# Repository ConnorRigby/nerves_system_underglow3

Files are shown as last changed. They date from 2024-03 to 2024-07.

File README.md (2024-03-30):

# ConeRGB Underglow3 Nerves Support



This is the base Nerves System configuration for [ConeRGB V3](https://github.com/connorrigby/underglow3).

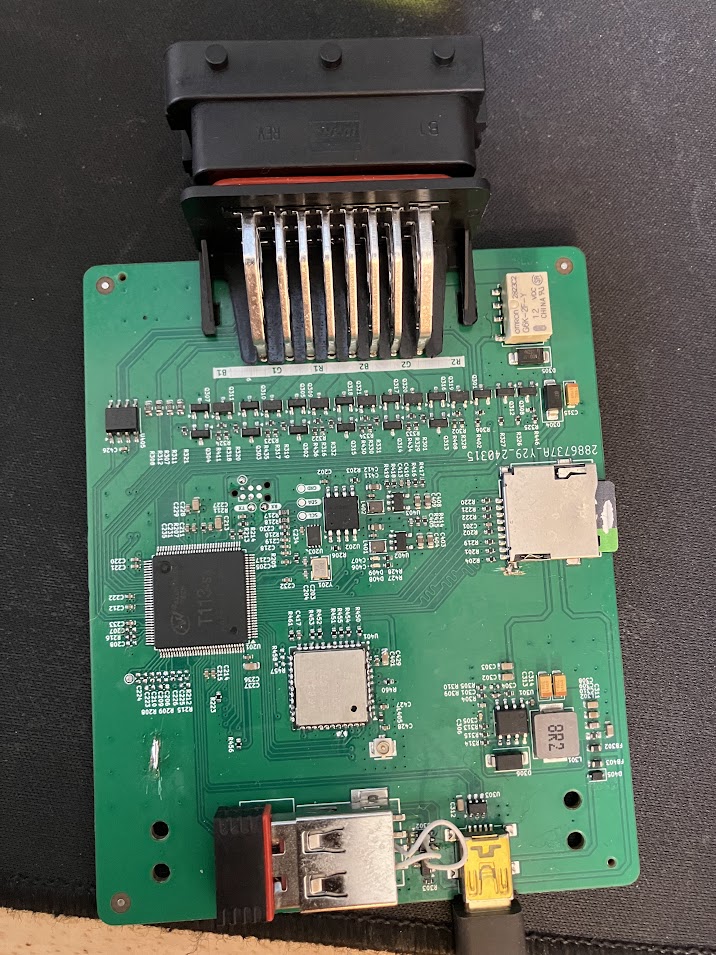
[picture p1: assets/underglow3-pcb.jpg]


| Feature | Description |
| --- | --- |
| CPU | 1.2 GHz ARM Cortex-A7 Dual-Core |
| Memory | 128 MB DDR3 |
| Storage | MicroSD |
| Linux kernel | 6.1 w/ patches |
| IEx terminal | UART `ttyS0` |
| GPIO, I2C, SPI | Yes - [Elixir Circuits](https://github.com/elixir-circuits) |
| Display | No |
| ADC | No |
| PWM | 8 channels |
| UART | ttyS0 |
| Camera | No |
| Ethernet | No |
| WiFi | Onboard WiFi |
| RTC | No |
| HW Watchdog | Yes |

## Special Thanks

Most of the hard work in this repo was gleamed from [YuzukiSBC](https://github.com/YuzukiHD/Buildroot-YuzukiSBC)

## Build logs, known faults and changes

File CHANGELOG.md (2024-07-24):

# Changelog

This project does NOT follow semantic versioning. The version increases as
follows:

1. Major version updates are breaking updates to the build infrastructure.
   These should be very rare.
2. Minor version updates are made for every major Buildroot release. This
   may also include Erlang/OTP and Linux kernel updates. These are made four
   times a year shortly after the Buildroot releases.
3. Patch version updates are made for Buildroot minor releases, Erlang/OTP
   releases, and Linux kernel updates. They're also made to fix bugs and add
   features to the build infrastructure.

## v0.3.0

Third prototype Bringup release

* Enable BlueZ
* Enable RTL WiFi

## v0.2.0

Second prototype Bringup release

* Enable ledc
* Enable temporary rtl wifi driver
* Enable kernel bluetooth
* Enable ipv6

## v0.1.0

This is the initial release.

* WiFi+BT does not work yet. next pcb revision required for brcmfmac.
* PWM works, leds in device tree. likely will change.
* LEDC works, leds in device tree. likely will change.
* user input configured but not tested.
* linux v6.7.1
* uboot 2024.04-rc4
* nerves_system_br v1.27.0

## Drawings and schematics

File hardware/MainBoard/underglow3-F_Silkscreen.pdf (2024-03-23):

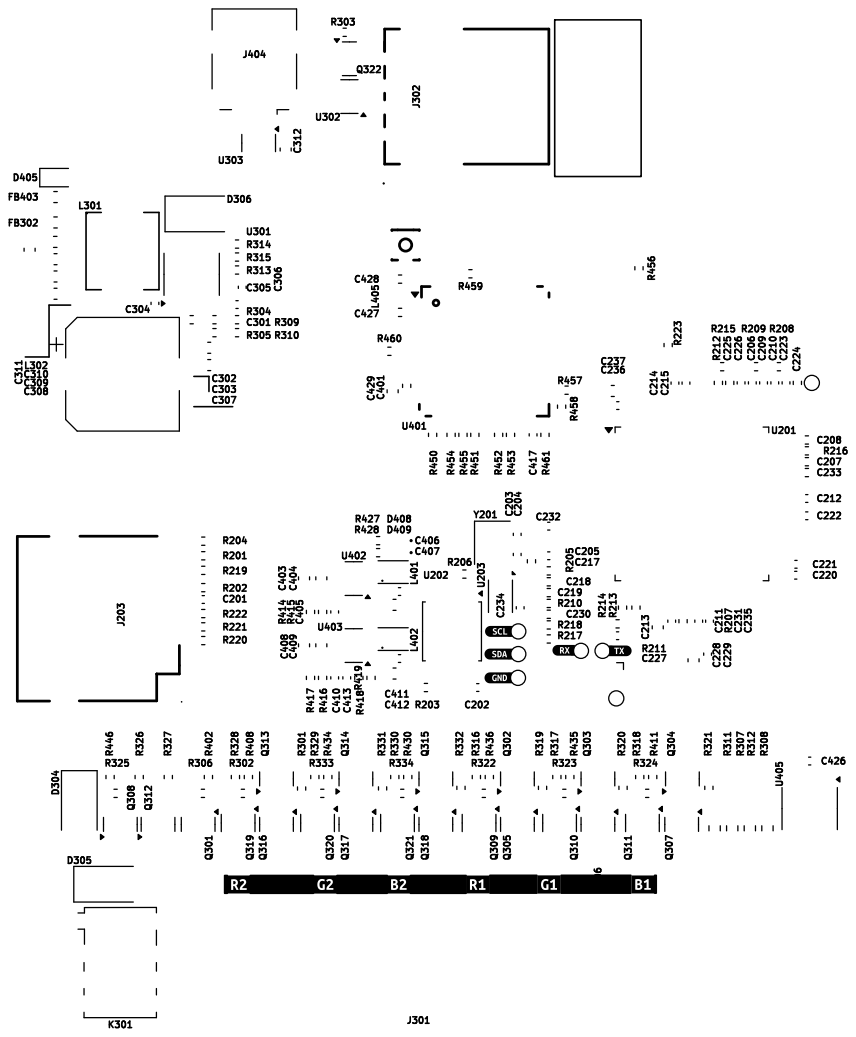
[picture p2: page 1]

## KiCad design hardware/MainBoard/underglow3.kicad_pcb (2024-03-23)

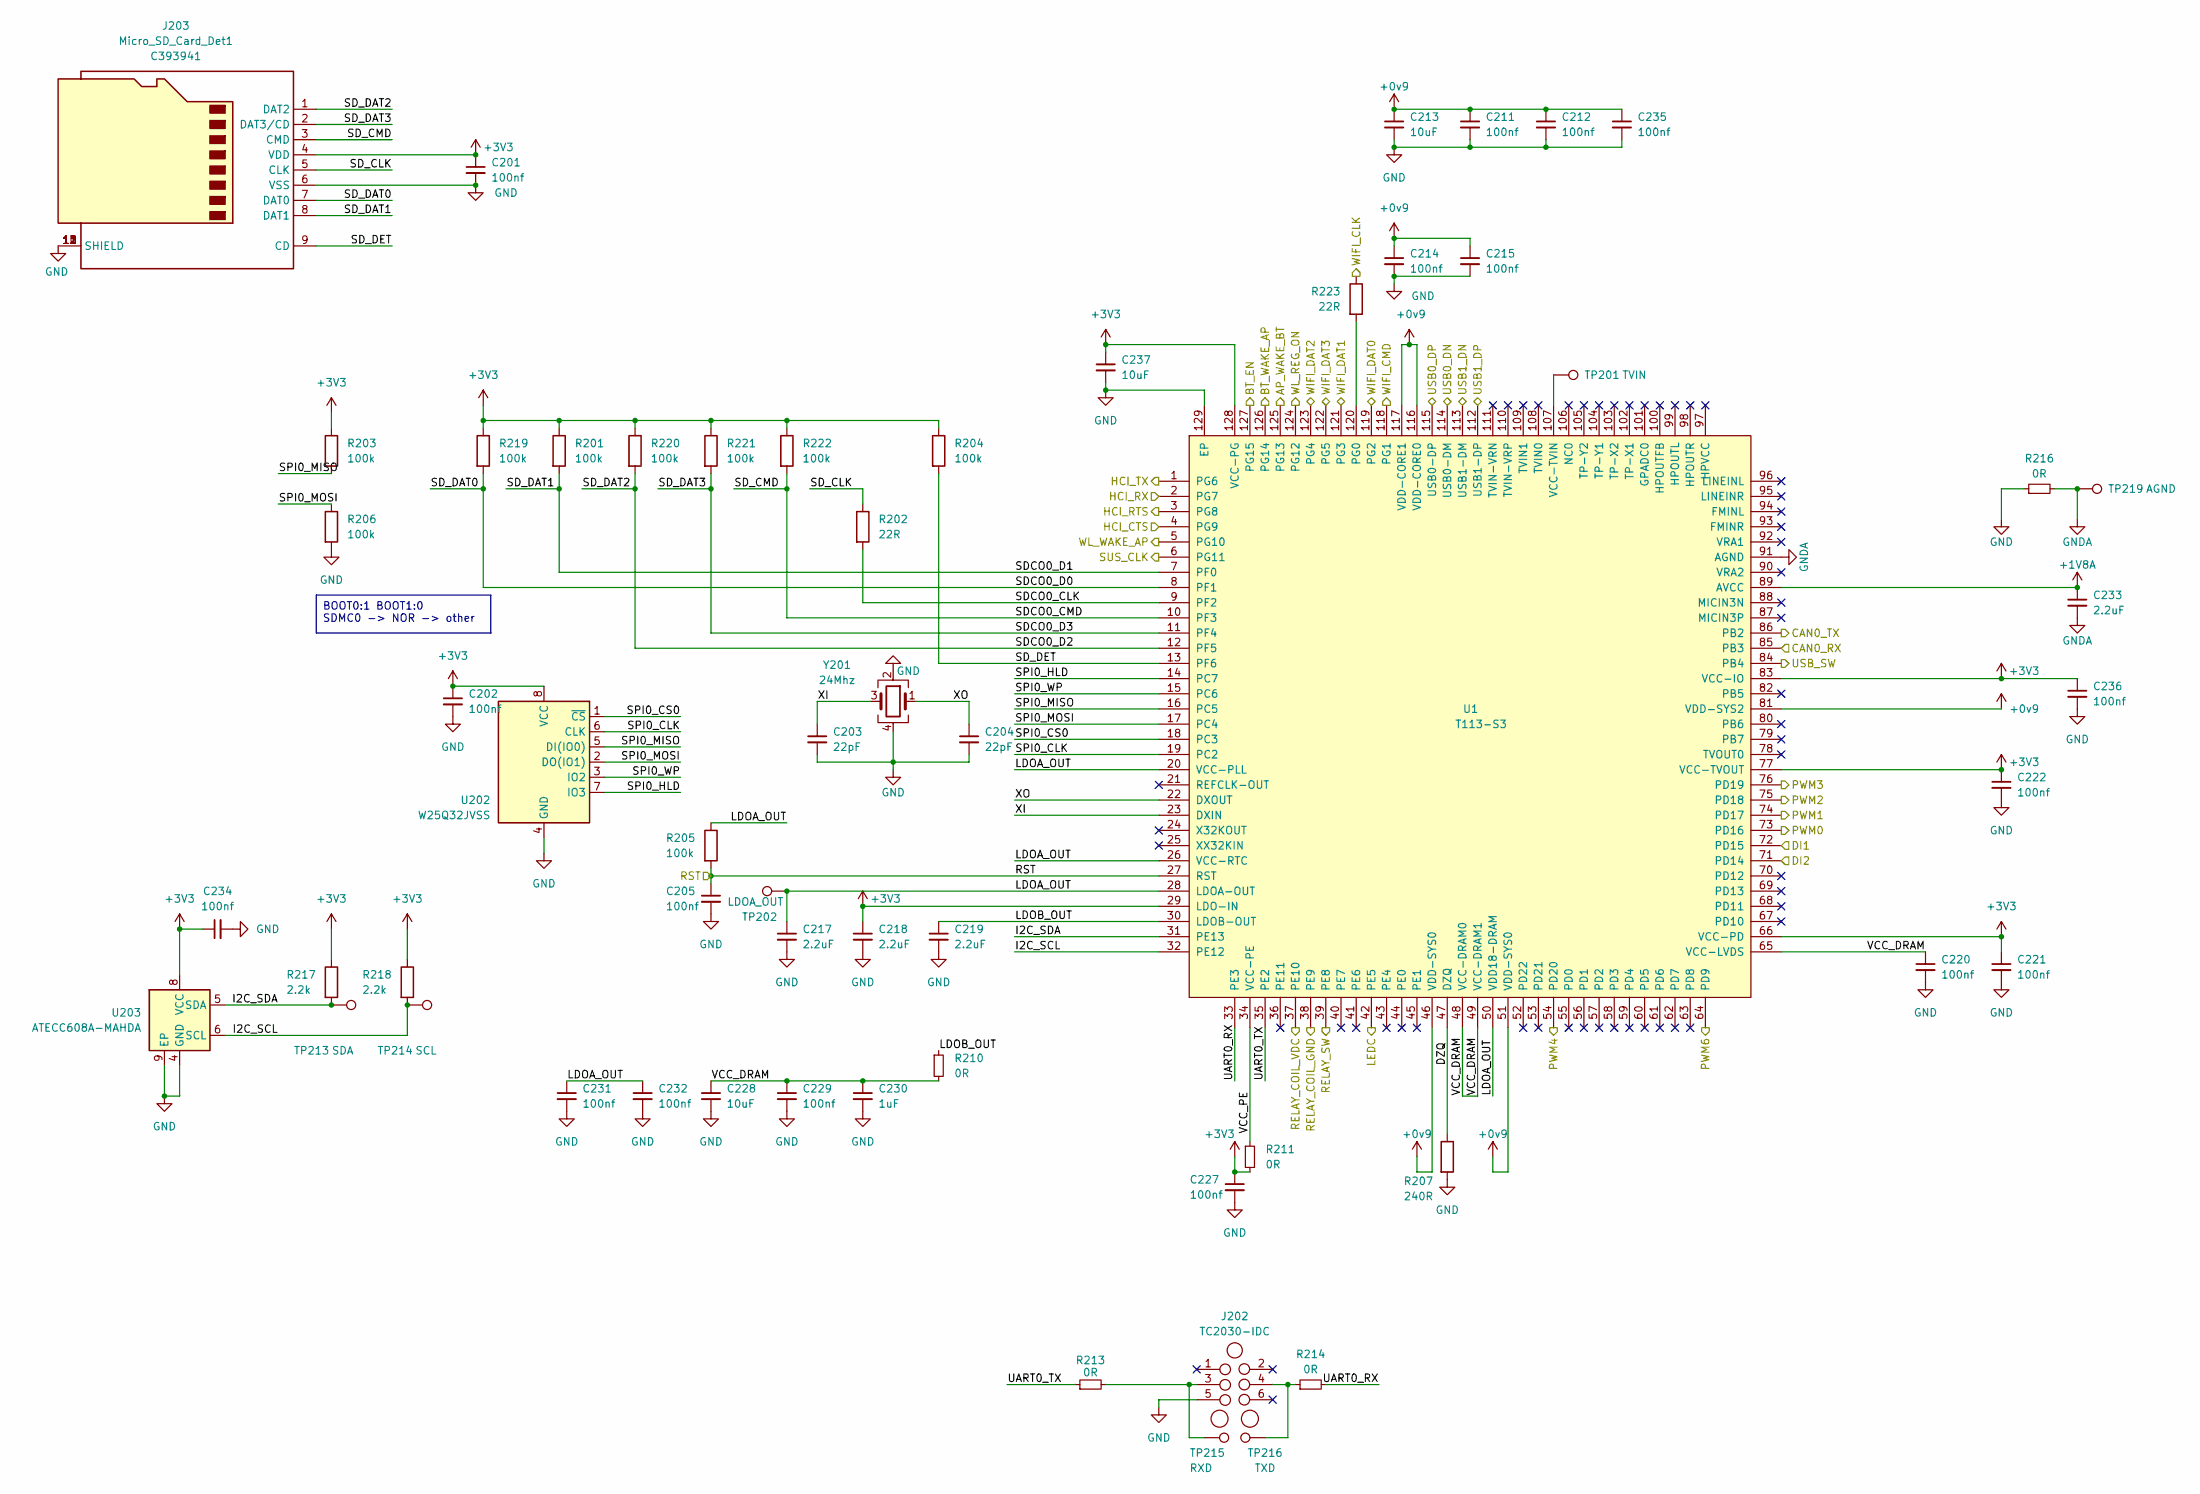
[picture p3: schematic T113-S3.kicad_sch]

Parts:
C201, C202, C205, C211, C212, C214, C215, C220, C221, C222, C227, C229, C231, C232, C234, C235, C236: 100nf; C_0402_1005Metric; MPN CL05B104KB54PNC; LCSC C307331
C203, C204: 22pF; C_0402_1005Metric; MPN 0402CG220J500NT; LCSC C1555
C213, C228, C237: 10uF; C_0603_1608Metric; MPN CL10A106MA8NRNC; LCSC C96446
C217, C218, C219, C233: 2.2uF; R_0402_1005Metric; MPN CL05A225MQ5NSNC; LCSC C12530
C230: 1uF; R_0402_1005Metric; MPN CL05A105KA5NQNC; LCSC C52923
J202: TC2030-IDC; Tag-Connect_TC2030-IDC-NL_2x03_P1.27mm_Vertical
J203: Micro_SD_Card_Det1; TF-SMD_TF-PUSH; MPN TF PUSH; LCSC C393941
R201, R203, R204, R205, R206, R219, R220, R221, R222: 100k; R_0402_1005Metric; MPN 0402WGF1003TCE; LCSC C25741
R202, R223: 22R; R_0402_1005Metric; MPN 0402WGF220JTCE; LCSC C25092
R207: 240R; R_0402_1005Metric; MPN 0402WGF2400TCE; LCSC C25094
R210, R211, R213, R214, R216: 0R; R_0402_1005Metric; MPN 0402WGF0000TCE; LCSC C17168
R217, R218: 2.2k; R_0402_1005Metric; MPN 0603WAF2201T5E; LCSC C4190
TP201: TVIN; TestPoint_Pad_D1.0mm
TP202: LDOA_OUT; TestPoint_Pad_D1.0mm
TP213: SDA; TestPoint_Pad_D1.0mm
TP214: SCL; TestPoint_Pad_D1.0mm
TP215: RXD; TestPoint_Pad_D1.0mm
TP216: TXD; TestPoint_Pad_D1.0mm
TP219: AGND; TestPoint_Pad_D1.0mm
U1: T113-S3; LQFP-128_L14.0-W14.0-P0.40-LS16.0-BL-EP5.6; MPN T113-S3; LCSC C5197687
U202: W25Q32JVSS; SOIC-8_5.23x5.23mm_P1.27mm; MPN W25Q32JVSSIQ; LCSC C179173
U203: ATECC608A-MAHDA; DFN-8-1EP_3x2mm_P0.5mm_EP1.3x1.5mm; MPN ATECC608A-MAHDA-S; LCSC C616908
Y201: 24Mhz; Crystal_SMD_3225-4Pin_3.2x2.5mm; MPN 3TJ424000XYFBC; LCSC C2149059

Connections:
+0v9: C211.1, C212.1, C213.1, C214.1, C215.1, C235.1; also elsewhere on the board
+1V8A: C233.1; also elsewhere on the board
+3V3: C201.1, C202.1, C218.1, C221.1, C222.1, C227.1, C234.1, C236.1, C237.1, J203.4 (VDD), R201.1, R203.1, R204.1, R211.2, R217.1, R218.1, R219.1, R220.1, R221.1, R222.1, U202.8 (VCC), U203.8 (VCC); also elsewhere on the board
/Application/DZQ: R207.1; also elsewhere on the board
/Application/I2C_SCL: R218.2, TP214.1, U203.6 (SCL); also elsewhere on the board
/Application/I2C_SDA: R217.2, TP213.1, U203.5 (SDA); also elsewhere on the board
/Application/LDOA_OUT: C217.1, C231.1, C232.1, R205.1, TP202.1; also elsewhere on the board
/Application/LDOB_OUT: C219.1, R210.1; also elsewhere on the board
/Application/RST: C205.1, R205.2; also elsewhere on the board
/Application/SDCO0_CLK: R202.2; also elsewhere on the board
/Application/SDCO0_CMD: J203.3 (CMD), R222.2; also elsewhere on the board
/Application/SDCO0_D0: J203.7 (DAT0), R219.2; also elsewhere on the board
/Application/SDCO0_D1: J203.8 (DAT1), R201.2; also elsewhere on the board
/Application/SDCO0_D2: J203.1 (DAT2), R220.2; also elsewhere on the board
/Application/SDCO0_D3: J203.2 (DAT3/CD), R221.2; also elsewhere on the board
/Application/SD_CLK: J203.5 (CLK), R202.1
/Application/SD_DET: J203.9 (CD), R204.2; also elsewhere on the board
/Application/SPI0_CLK: U202.6 (CLK); also elsewhere on the board
/Application/SPI0_CS0: U202.1 (~CS); also elsewhere on the board
/Application/SPI0_HLD: U202.7 (IO3); also elsewhere on the board
/Application/SPI0_MISO: R203.2, U202.5 (DI(IO0)); also elsewhere on the board
/Application/SPI0_MOSI: R206.1, U202.2 (DO(IO1)); also elsewhere on the board
/Application/SPI0_WP: U202.3 (IO2); also elsewhere on the board
/Application/UART0_RX: R214.2; also elsewhere on the board
/Application/UART0_TX: R213.1; also elsewhere on the board
/Application/VCC_DRAM: C220.1, C228.1, C229.1, C230.1, R210.2; also elsewhere on the board
/Application/VCC_PE: R211.1; also elsewhere on the board
/Application/WIFI_CLK: R223.1; also elsewhere on the board
/Application/XI: C203.1, Y201.3; also elsewhere on the board
/Application/XO: C204.1, Y201.1; also elsewhere on the board
GND: C201.2, C202.2, C203.2, C204.2, C205.2, C211.2, C212.2, C213.2, C214.2, C215.2, C217.2, C218.2, C219.2, C220.2, C221.2, C222.2, C227.2, C228.2, C229.2, C230.2, C231.2, C232.2, C234.2, C235.2, C236.2, C237.2, J202.5, J203.6 (VSS), J203.10 (SHIELD), J203.11 (SHIELD), J203.12 (SHIELD), J203.13 (SHIELD), R206.2, R207.2, R216.1, U202.4 (GND), U203.4 (GND), U203.9 (EP), Y201.2, Y201.4; also elsewhere on the board
GNDA: C233.2, R216.2, TP219.1; also elsewhere on the board
unnamed: J202.3, R213.2, TP215.1
unnamed: J202.4, R214.1, TP216.1
unnamed 127: R223.2; also elsewhere on the board
unnamed 128: TP201.1; also elsewhere on the board

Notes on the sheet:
BOOT0:1 BOOT1:0 SDMC0 -> NOR -> other

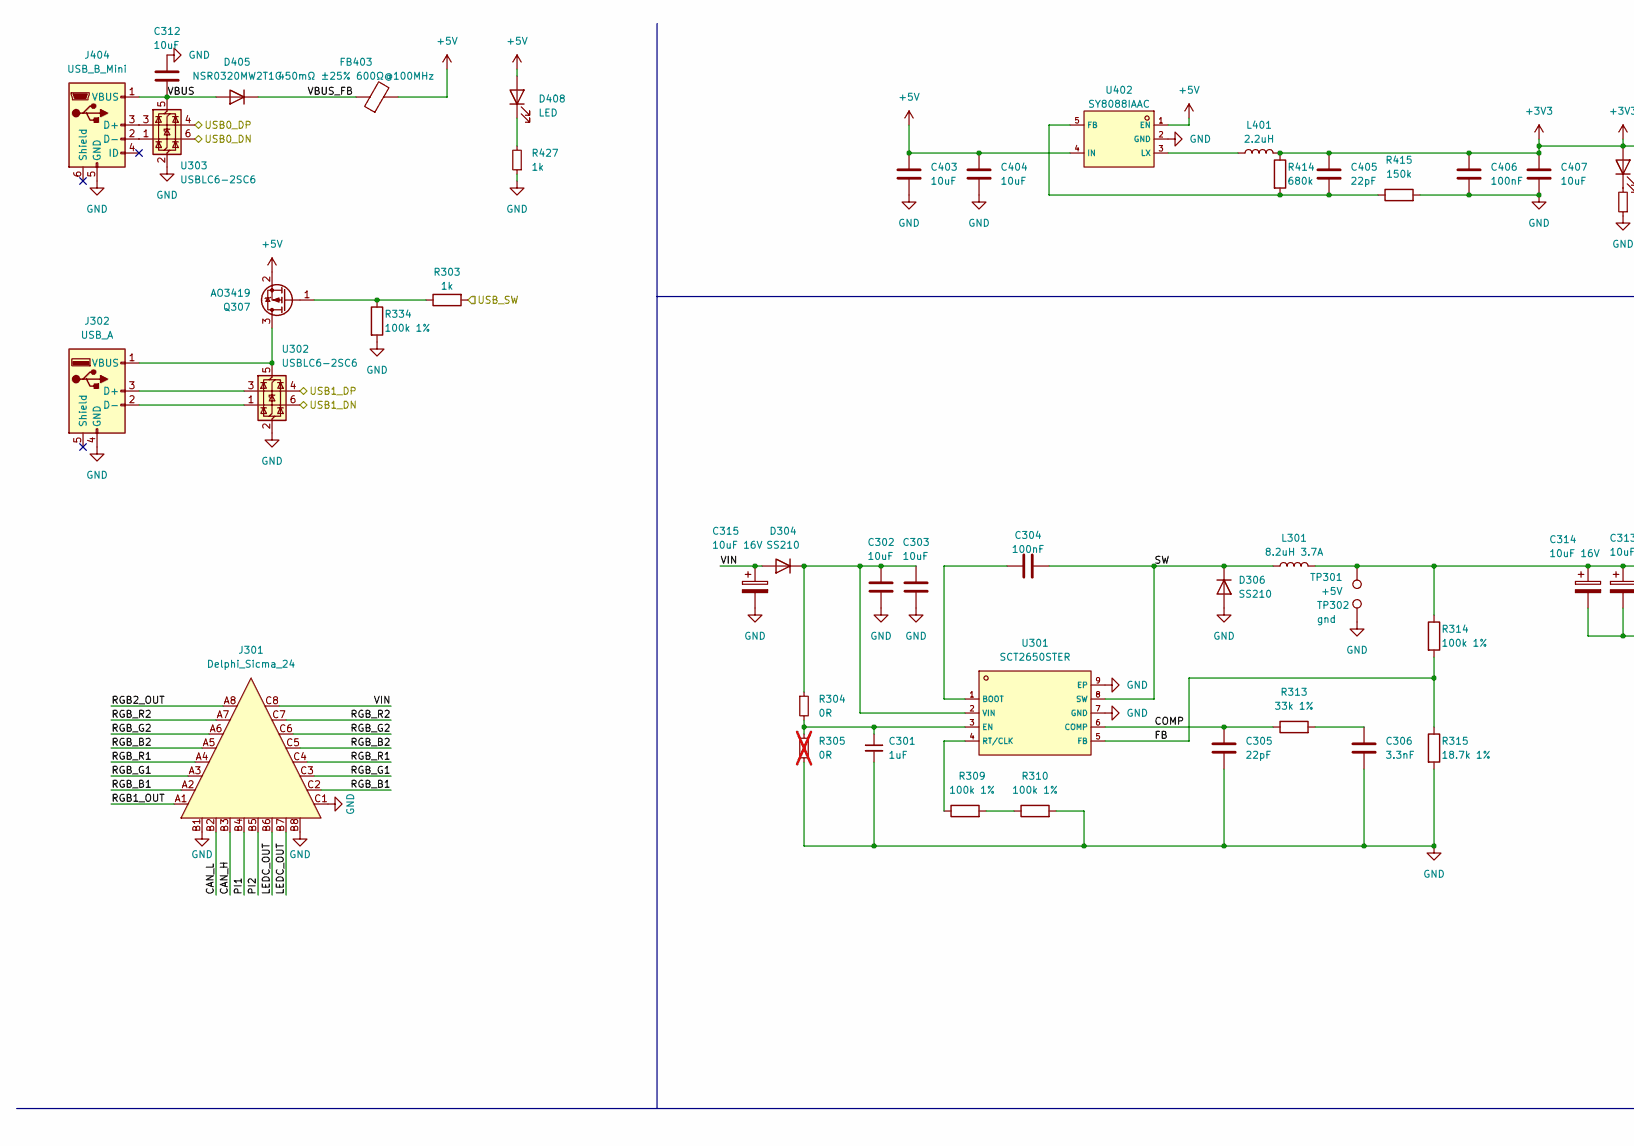
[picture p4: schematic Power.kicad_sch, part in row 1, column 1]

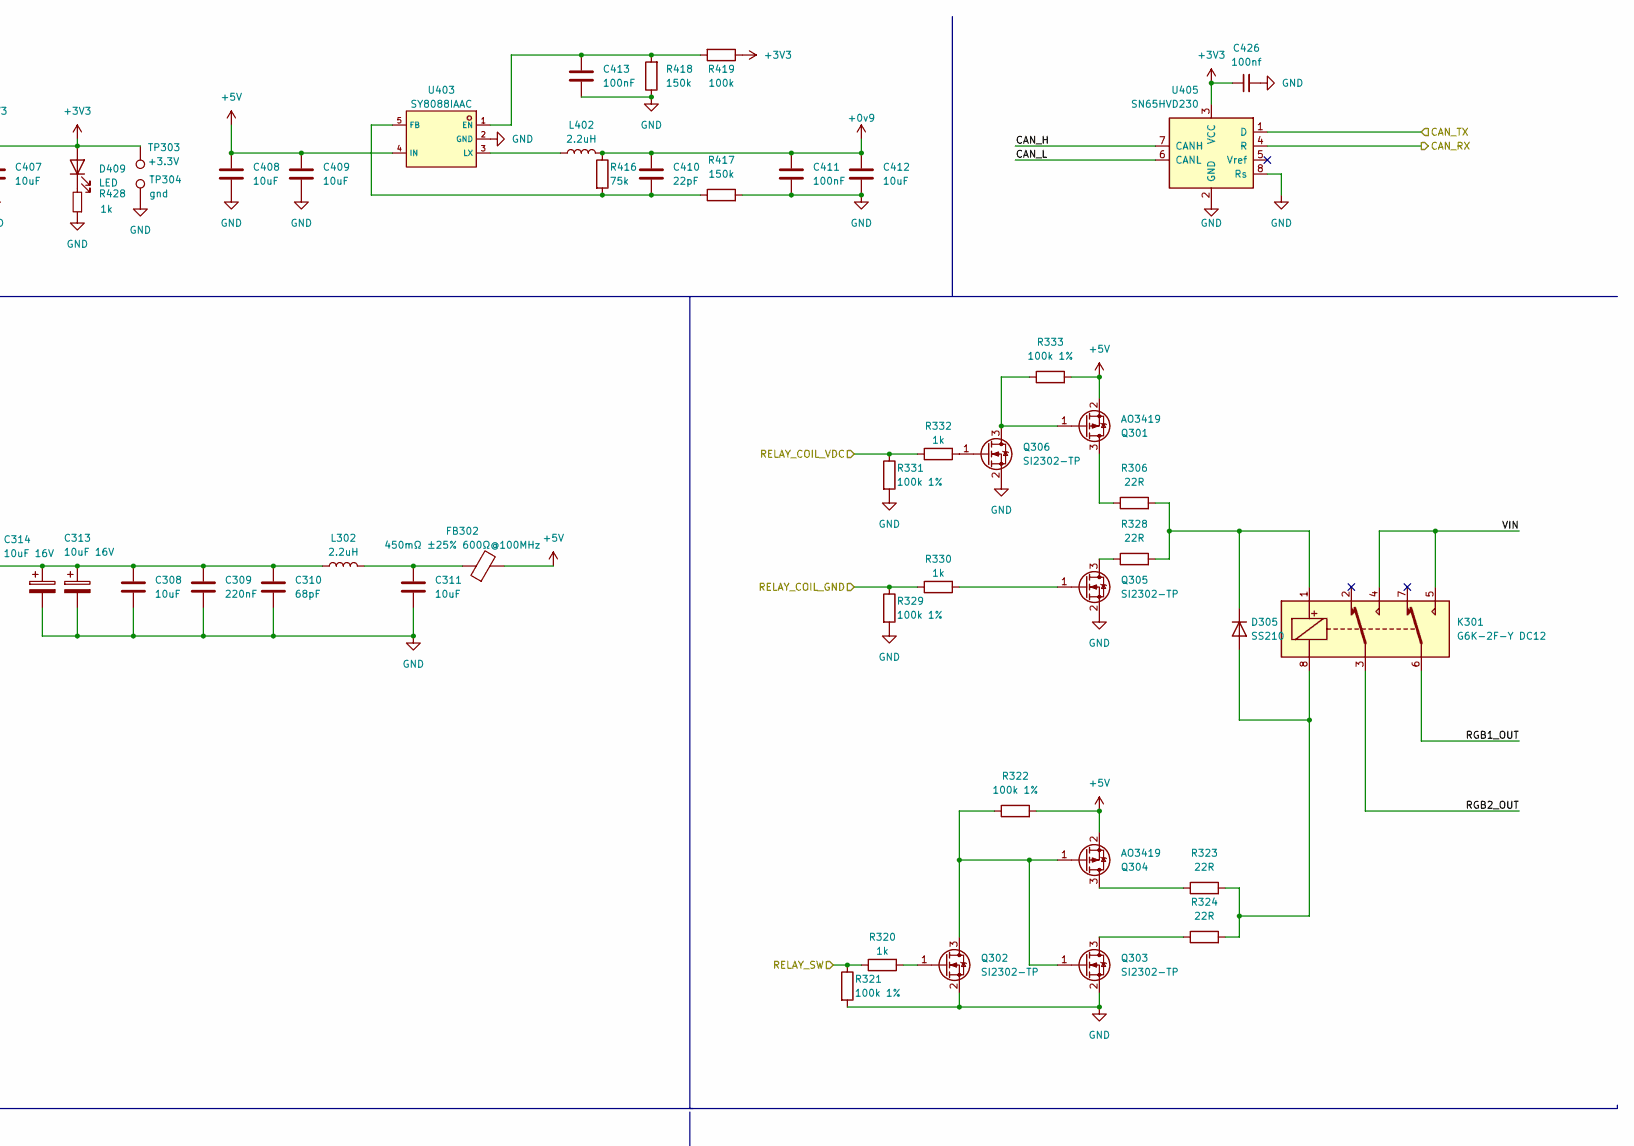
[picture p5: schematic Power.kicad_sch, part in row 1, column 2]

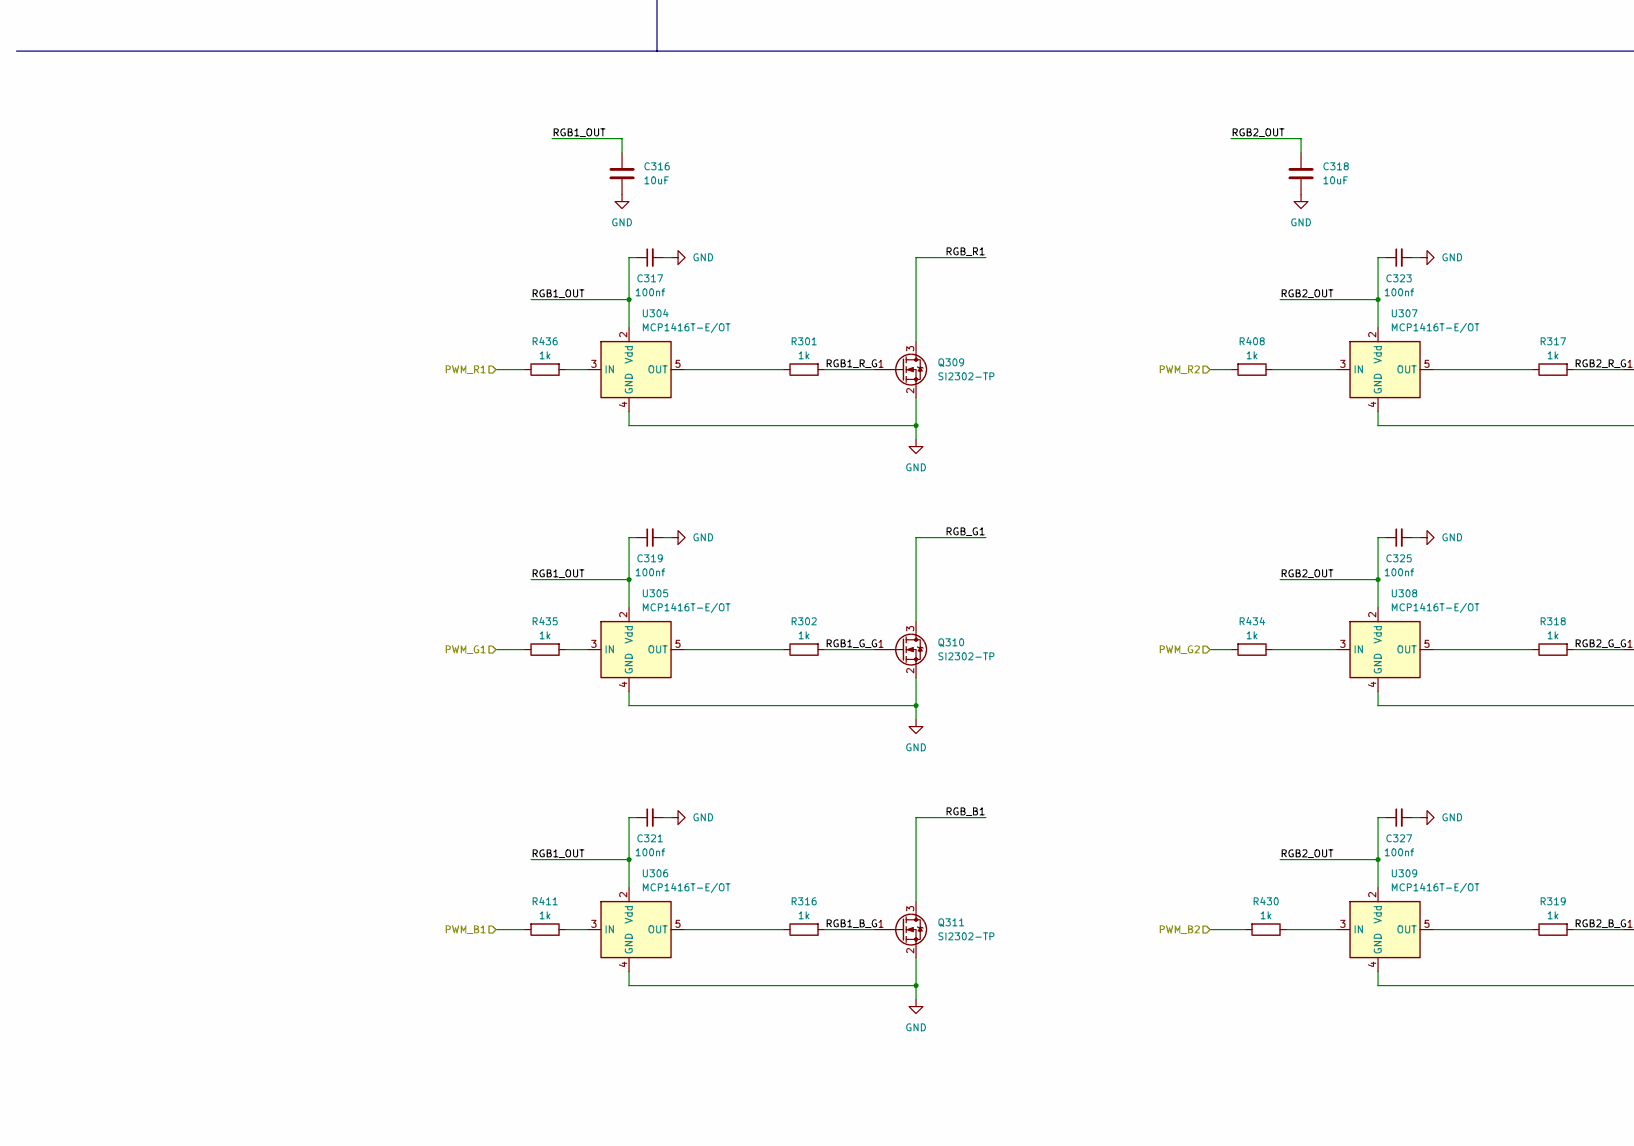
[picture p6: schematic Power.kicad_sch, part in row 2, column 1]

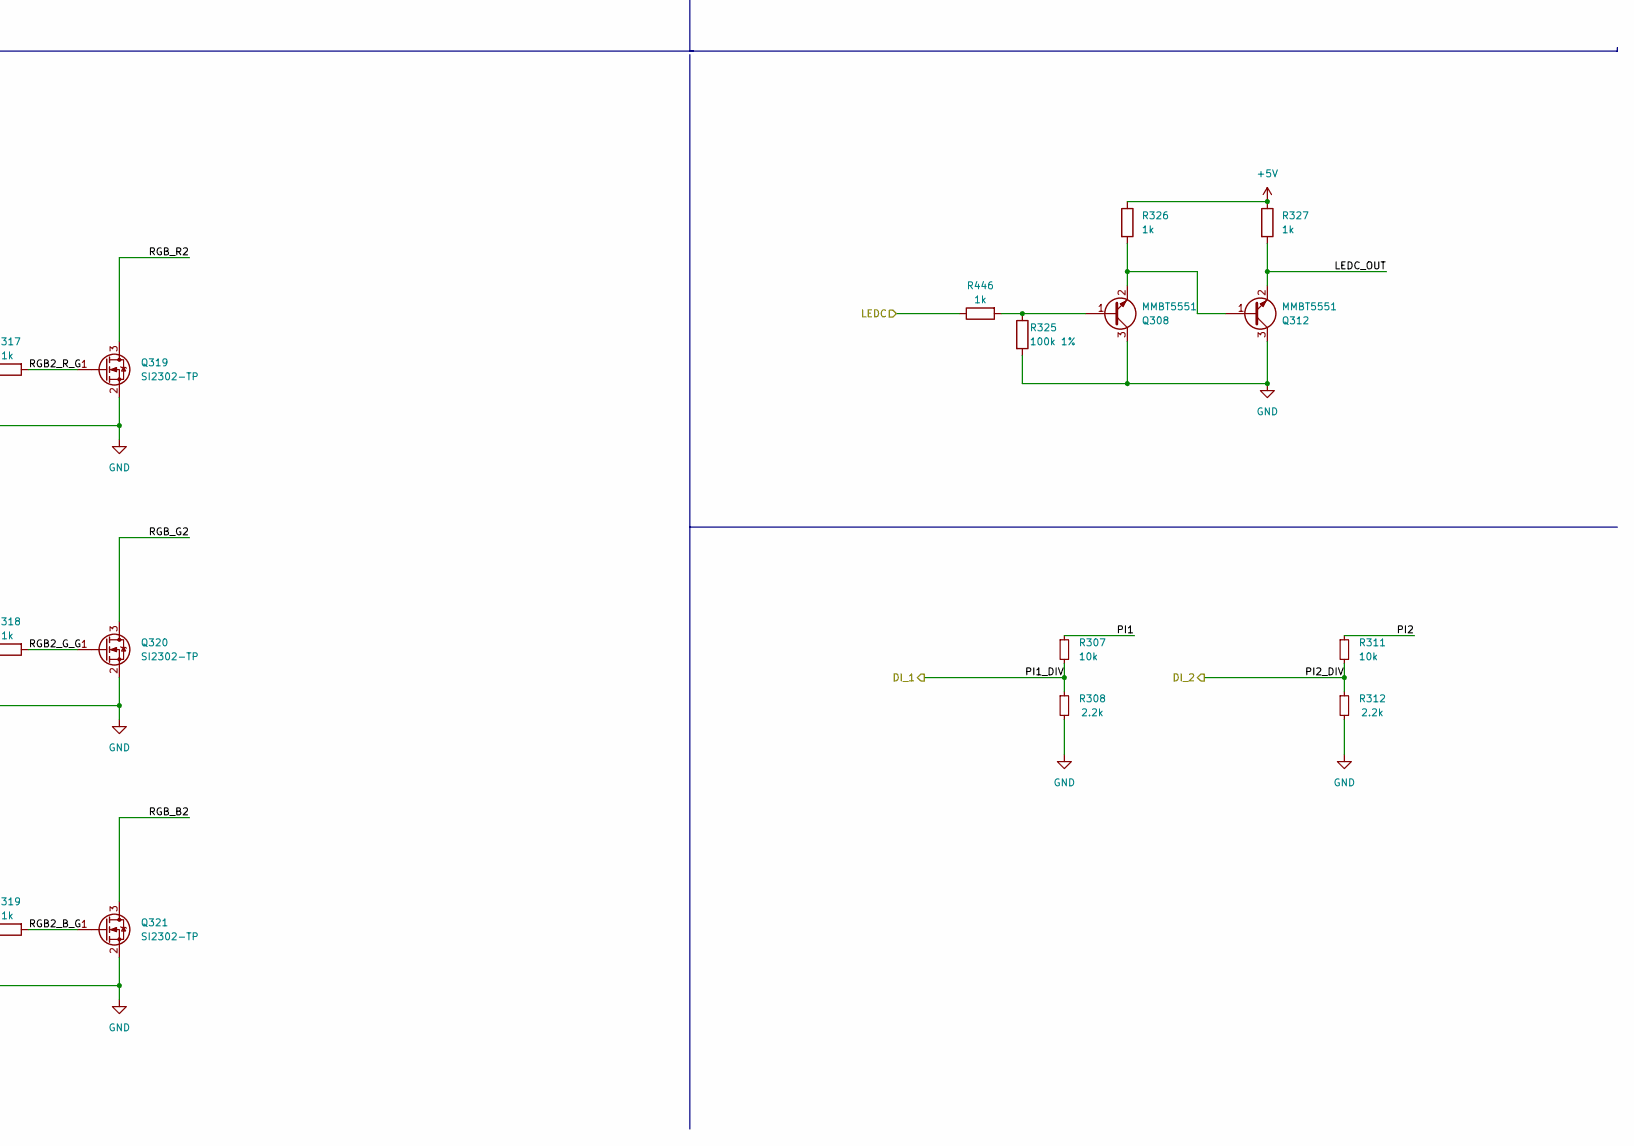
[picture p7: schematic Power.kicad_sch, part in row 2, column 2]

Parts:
C301: 1uF; R_0402_1005Metric; MPN CL05A105KA5NQNC; LCSC C52923
C302, C303, C308, C311, C312: 10uF; C_0603_1608Metric; MPN CL10A106MA8NRNC; LCSC C96446
C304, C406, C411, C413: 100nF; C_0402_1005Metric; MPN CL05B104KB54PNC; LCSC C307331
C305, C405, C410: 22pF; C_0402_1005Metric; MPN 0402CG220J500NT; LCSC C1555
C306: 3.3nF; C_0402_1005Metric; MPN CL05B332KB5NNNC; LCSC C26404
C309: 220nF; C_0603_1608Metric; MPN CL10B224KA8NNNC; LCSC C21120
C310: 68pF; C_0603_1608Metric; MPN CL10C680JB8NNNC; LCSC C28262
C313, C314, C315: 10uF 16V; CP_EIA-3216-18_Kemet-A; MPN TAJA106K016RNJ; LCSC C7171
C316, C318, C403, C404, C407, C408, C409, C412: 10uF; C_0603_1608Metric; MPN C0603X5R106M100NT; LCSC C466780
C317, C319, C321, C323, C325, C327, C426: 100nf; C_0402_1005Metric; MPN CL05B104KB54PNC; LCSC C307331
D304, D305, D306: SS210; D_SMA; MPN SS210; LCSC C14996
D405: NSR0320MW2T1G; D_SOD-323; MPN 1N5819WS; LCSC C191023
D408, D409: LED; LED_0402_1005Metric; MPN LTST-C281KRKT; LCSC C364556
FB302, FB403: 450mΩ ±25% 600Ω@100MHz; L_0603_1608Metric; MPN GZ1608D601TF; LCSC C1002
J301: Delphi_Sicma_24; Delphi_Sicma_24_Black
J302: USB_A; USB-A-SMD_USB-234-BCW; MPN USB-234-BCW; LCSC C720528
J404: USB_B_Mini; USB_Mini-B_Lumberg_2486_01_Horizontal; MPN UX-144S-ACP5; LCSC C720611
K301: G6K-2F-Y DC12; Relay_DPDT_Omron_G6K-2F-Y; MPN G6K-2F-Y DC12; LCSC C397194
L301: 8.2uH 3.7A; IND-SMD_L7.0-W6.6_FXL0630; MPN SLO0624H8R2MTT; LCSC C325977
L302: 2.2uH; L_0603_1608Metric; MPN 0402WGF0000TCE; LCSC C17168
L401, L402: 2.2uH; IND-SMD_L2.0-W1.6_VLS201610CX-150M; MPN WPN201610H2R2MT; LCSC C97005
Q301, Q304, Q307: AO3419; SOT-23W; MPN AO3419; LCSC C88053
Q302, Q303, Q305, Q306: SI2302-TP; SOT-23; MPN SI2302-TP; LCSC C77977
Q308, Q312: MMBT5551; SOT-23; MPN MMBT5551; LCSC C2145
Q309, Q310, Q311, Q319, Q320, Q321: SI2302-TP; SOT-23-3; MPN AO3400A; LCSC C20917
R301, R302, R303, R316, R317, R318, R319, R320, R326, R327, R330, R332, R408, R411, R427, R428, R430, R434, R435, R436, R446: 1k; R_0402_1005Metric; MPN 0402WGF1001TCE; LCSC C11702
R304: 0R; R_0402_1005Metric; MPN 0402WGF0000TCE; LCSC C17168
R305: 0R; R_0402_1005Metric; MPN 0402WGF0000TCE; LCSC C17168; not fitted
R306, R323, R324, R328: 22R; R_0402_1005Metric; MPN 0402WGF220JTCE; LCSC C25092
R307, R311: 10k; R_0603_1608Metric; MPN 0603WAF1002T5E; LCSC C25804
R308, R312: 2.2k; R_0603_1608Metric; MPN 0603WAF2201T5E; LCSC C4190
R309, R310, R314, R321, R322, R325, R329, R331, R333, R334: 100k 1%; R_0402_1005Metric; MPN 0402WGF1003TCE; LCSC C25741
R313: 33k 1%; R_0402_1005Metric; MPN 0402WGF3302TCE; LCSC C25779
R315: 18.7k 1%; R_0402_1005Metric; MPN 0402WGF1872TCE; LCSC C11476
R414: 680k; R_0402_1005Metric; MPN 0402WGF6803TCE; LCSC C4131
R415, R417, R418: 150k; R_0402_1005Metric; MPN 0402WGF1503TCE; LCSC C25755
R416: 75k; R_0402_1005Metric; MPN 0402WGF7502TCE; LCSC C25798
R419: 100k; R_0402_1005Metric; MPN 0402WGF1003TCE; LCSC C25741
TP301: +5V; TestPoint_Pad_D1.0mm
TP302, TP304: gnd; TestPoint_Pad_D1.0mm
TP303: +3.3V; TestPoint_Pad_D1.0mm
U301: SCT2650STER; HSOP-8-1EP_3.9x4.9mm_P1.27mm_EP2.41x3.1mm; MPN SCT2650STER; LCSC C2840771
U302, U303: USBLC6-2SC6; SOT-23-6; MPN USBLC6-2SC6; LCSC C2827654
U304, U305, U306, U307, U308, U309: MCP1416T-E/OT; SOT-23-5; LCSC C83775
U402, U403: SY8088IAAC; SOT-23-5; MPN SY8088IAAC; LCSC C479072
U405: SN65HVD230; SOIC-8_3.9x4.9mm_P1.27mm; MPN SN65HVD230DR; LCSC C12084

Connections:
+0v9: C410.1, C411.1, C412.1, L402.2, R416.1; also elsewhere on the board
+3V3: C405.1, C406.1, C407.1, C426.1, D409.2 (A), L401.2, R414.1, R419.1, TP303.1, U405.3 (VCC); also elsewhere on the board
+5V: C403.1, C404.1, C408.1, C409.1, D408.2 (A), FB302.2, FB403.2, Q301.2 (S), Q304.2 (S), Q307.2 (S), R322.2, R326.1, R327.1, R333.2, U402.1 (EN), U402.4 (IN), U403.4 (IN)
/Application/CAN0_RX: U405.4 (R); also elsewhere on the board
/Application/CAN0_TX: U405.1 (D); also elsewhere on the board
/Application/LEDC: R446.1; also elsewhere on the board
/Application/PWM0: R430.2; also elsewhere on the board
/Application/PWM1: R436.1; also elsewhere on the board
/Application/PWM2: R435.1; also elsewhere on the board
/Application/PWM3: R411.2; also elsewhere on the board
/Application/PWM4: R408.2; also elsewhere on the board
/Application/PWM6: R434.2; also elsewhere on the board
/Application/RELAY_COIL_GND: R329.1, R330.1; also elsewhere on the board
/Application/RELAY_COIL_VDC: R331.1, R332.1; also elsewhere on the board
/Application/RELAY_SW: R320.1, R321.1; also elsewhere on the board
/Application/USB0_DN: U303.6 (I/O1); also elsewhere on the board
/Application/USB0_DP: U303.4 (I/O2); also elsewhere on the board
/Application/USB1_DN: U302.6 (I/O1); also elsewhere on the board
/Application/USB1_DP: U302.4 (I/O2); also elsewhere on the board
/Application/USB_SW: R303.2; also elsewhere on the board
/Power/CAN_H: J301.B3, U405.7 (CANH)
/Power/CAN_L: J301.B2, U405.6 (CANL)
/Power/COMP: C305.1, R313.1, U301.6 (COMP)
/Power/FB: R314.2, R315.1, U301.5 (FB)
/Power/LEDC_OUT: J301.B6, J301.B7, Q312.2 (E), R327.2
/Power/PI1: J301.B4, R307.1
/Power/PI1_DIV: R307.2, R308.1; also elsewhere on the board
/Power/PI2: J301.B5, R311.1
/Power/PI2_DIV: R311.2, R312.1; also elsewhere on the board
/Power/RGB1_B_G: Q311.1 (G), R316.2
/Power/RGB1_G_G: Q310.1 (G), R302.2
/Power/RGB1_OUT: C316.1, C317.1, C319.1, C321.1, J301.A1, K301.6, U304.2 (Vdd), U305.2 (Vdd), U306.2 (Vdd)
/Power/RGB1_R_G: Q309.1 (G), R301.2
/Power/RGB2_B_G: Q321.1 (G), R319.2
/Power/RGB2_G_G: Q320.1 (G), R318.2
/Power/RGB2_OUT: C318.1, C323.1, C325.1, C327.1, J301.A8, K301.3, U307.2 (Vdd), U308.2 (Vdd), U309.2 (Vdd)
/Power/RGB2_R_G: Q319.1 (G), R317.2
/Power/RGB_B1: J301.A2, J301.C2, Q311.3 (D)
/Power/RGB_B2: J301.A5, J301.C5, Q321.3 (D)
/Power/RGB_G1: J301.A3, J301.C3, Q310.3 (D)
/Power/RGB_G2: J301.A6, J301.C6, Q320.3 (D)
/Power/RGB_R1: J301.A4, J301.C4, Q309.3 (D)
/Power/RGB_R2: J301.A7, J301.C7, Q319.3 (D)
/Power/SW: C304.2, D306.1 (K), L301.1, U301.8 (SW)
/Power/VBUS: C312.2, D405.2 (A), J404.1 (VBUS), U303.5 (VBUS)
/Power/VBUS_FB: D405.1 (K), FB403.1
/Power/VIN: C315.1, D304.2 (A), J301.C8, K301.4, K301.5
GND: C301.2, C302.2, C303.2, C305.2, C306.2, C308.2, C309.2, C310.2, C311.2, C312.1, C313.2, C314.2, C315.2, C316.2, C317.2, C318.2, C319.2, C321.2, C323.2, C325.2, C327.2, C403.2, C404.2, C406.2, C407.2, C408.2, C409.2, C411.2, C412.2, C413.2, C426.2, D306.2 (A), J301.B1, J301.B8, J301.C1, J302.4 (GND), J404.5 (GND), Q302.2 (S), Q303.2 (S), Q305.2 (S), Q306.2 (S), Q308.3 (C), Q309.2 (S), Q310.2 (S), Q311.2 (S), Q312.3 (C), Q319.2 (S), Q320.2 (S), Q321.2 (S), R305.2, R308.2, R310.2, R312.2, R315.2, R321.2, R325.2, R329.2, R331.2, R334.2, R415.2, R417.2, R418.1, R427.1, R428.1, TP302.1, TP304.1, U301.7 (GND), U301.9 (EP), U302.2 (GND), U303.2 (GND), U304.4 (GND), U305.4 (GND), U306.4 (GND), U307.4 (GND), U308.4 (GND), U309.4 (GND), U402.2 (GND), U403.2 (GND), U405.2 (GND), U405.8 (Rs); also elsewhere on the board
unnamed: C306.1, R313.2
unnamed: C308.1, C309.1, C310.1, C313.1, C314.1, L301.2, L302.1, R314.1, TP301.1
unnamed: C311.1, FB302.1, L302.2
unnamed: C302.1, C303.1, D304.1 (K), R304.1, U301.2 (VIN)
unnamed: D305.2 (A), K301.8, R323.2, R324.2
unnamed: D305.1 (K), K301.1, R306.2, R328.2
unnamed: D408.1 (K), R427.2
unnamed: D409.1 (K), R428.2
unnamed: J302.3 (D+), U302.3 (I/O2)
unnamed: J302.2 (D-), U302.1 (I/O1)
unnamed: J302.1 (VBUS), Q307.3 (D), U302.5 (VBUS)
unnamed: J404.3 (D+), U303.3 (I/O2)
unnamed: J404.2 (D-), U303.1 (I/O1)
unnamed: Q301.3 (D), R306.1
unnamed: Q301.1 (G), Q306.3 (D), R333.1
unnamed: Q302.3 (D), Q303.1 (G), Q304.1 (G), R322.1
unnamed: Q302.1 (G), R320.2
unnamed: Q303.3 (D), R324.1
unnamed: Q304.3 (D), R323.1
unnamed: Q305.3 (D), R328.1
unnamed: Q305.1 (G), R330.2
unnamed: Q306.1 (G), R332.2
unnamed: Q307.1 (G), R303.1, R334.1
unnamed: Q308.1 (B), R325.1, R446.2
unnamed: Q308.2 (E), Q312.1 (B), R326.2
unnamed: R309.2, R310.1
unnamed: C304.1, U301.1 (BOOT)
unnamed: C301.1, R304.2, R305.1, U301.3 (EN)
unnamed: R309.1, U301.4 (RT/CLK)
unnamed: R436.2, U304.3 (IN)
unnamed: R301.1, U304.5 (OUT)
unnamed: R435.2, U305.3 (IN)
unnamed: R302.1, U305.5 (OUT)
unnamed: R411.1, U306.3 (IN)
unnamed: R316.1, U306.5 (OUT)
unnamed: R408.1, U307.3 (IN)
unnamed: R317.1, U307.5 (OUT)
unnamed: R434.1, U308.3 (IN)
unnamed: R318.1, U308.5 (OUT)
unnamed: R430.1, U309.3 (IN)
unnamed: R319.1, U309.5 (OUT)
unnamed: C405.2, R414.2, R415.1, U402.5 (FB)
unnamed: L401.1, U402.3 (LX)
unnamed: C413.1, R418.2, R419.2, U403.1 (EN)
unnamed: C410.2, R416.2, R417.1, U403.5 (FB)
unnamed: L402.1, U403.3 (LX)

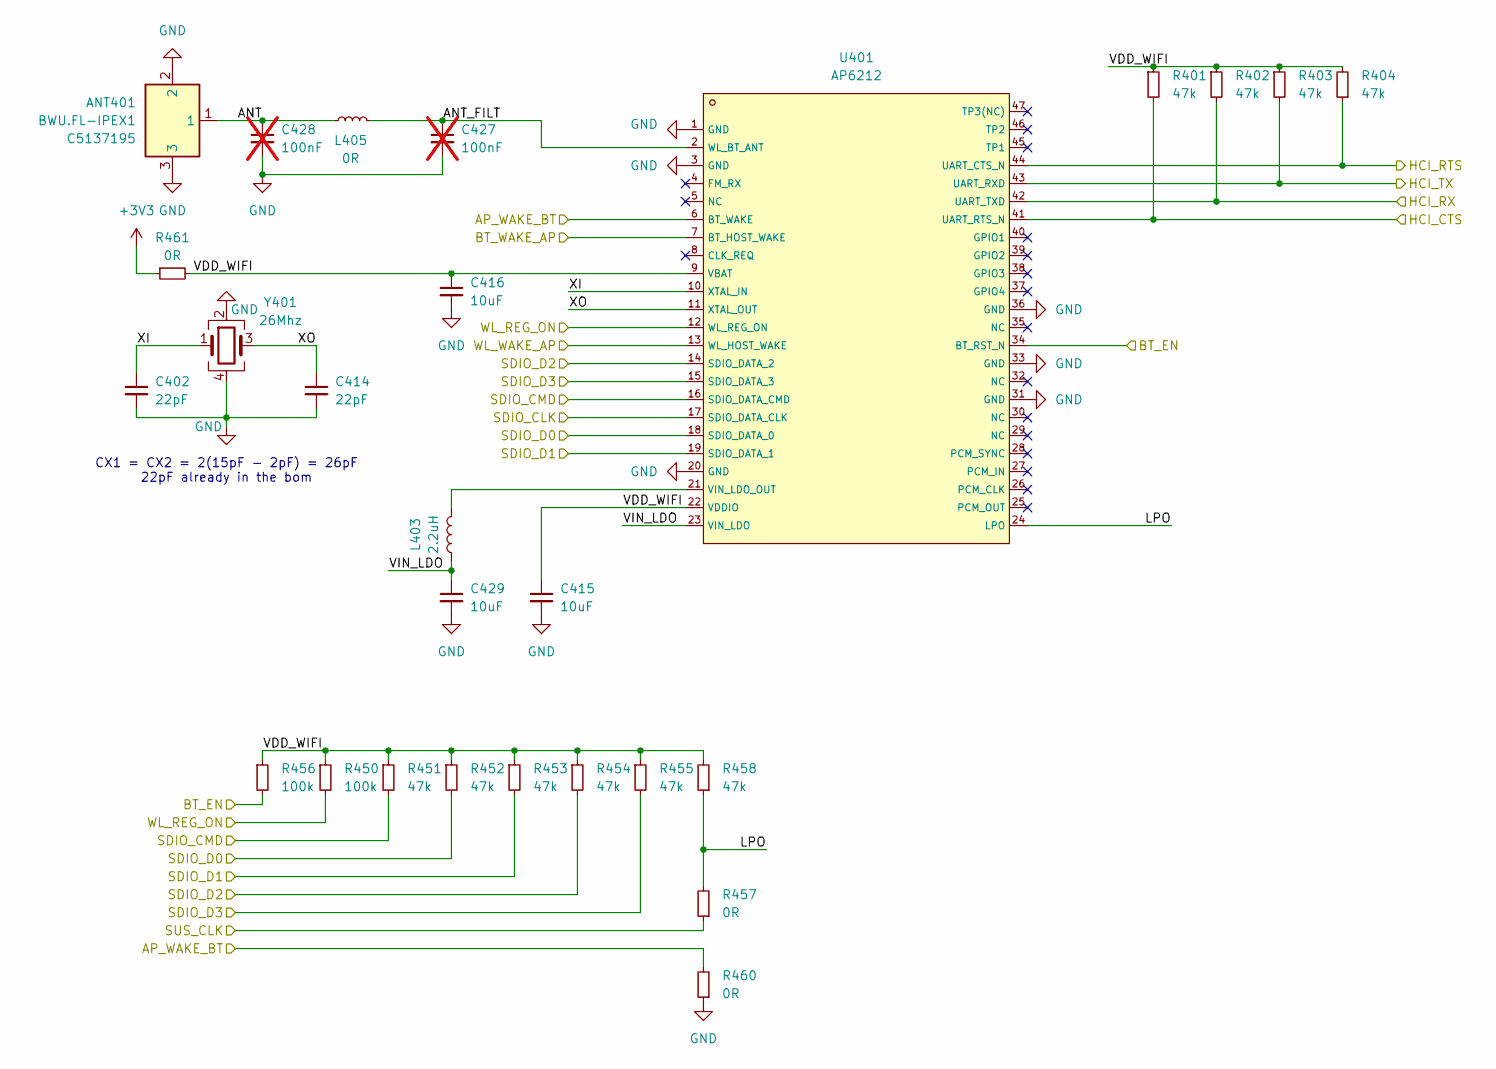
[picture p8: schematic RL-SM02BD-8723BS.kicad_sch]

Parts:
ANT401: BWU.FL-IPEX1; IPEX-SMD_BWIPX-1-001E; MPN BWU.FL-IPEX1; LCSC C5137195
C402, C414: 22pF; C_0402_1005Metric; MPN 0402CG220J500NT; LCSC C1555
C415, C416, C429: 10uF; C_0603_1608Metric; MPN CL10A106MA8NRNC; LCSC C96446
C427, C428: 100nF; R_0402_1005Metric; MPN CL05B104KB54PNC; LCSC C307331; not fitted
L403: 2.2uH; L_0603_1608Metric; MPN 0402WGF0000TCE; LCSC C17168
L405: 0R; R_0402_1005Metric; MPN 0402WGF0000TCE; LCSC C17168
R401, R402, R403, R404, R451, R452, R453, R454, R455, R458: 47k; R_0402_1005Metric; MPN 0402WGF4702TCE; LCSC C25792
R450, R456: 100k; R_0402_1005Metric; MPN 0402WGF1003TCE; LCSC C25741
R457, R460, R461: 0R; R_0402_1005Metric; MPN 0402WGF0000TCE; LCSC C17168
U401: AP6212; QFN-44_L12.0-W12.0-P0.90-TL_AP6212; LCSC C2798300
Y401: 26Mhz; Crystal_SMD_3225-4Pin_3.2x2.5mm; MPN TAXM26M4RHBCCT2T; LCSC C516065

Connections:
+3V3: R461.1; also elsewhere on the board
/Application/AP_WAKE_BT: R460.2, U401.6 (BT_WAKE); also elsewhere on the board
/Application/BT_EN: R456.2, U401.34 (BT_RST_N); also elsewhere on the board
/Application/BT_WAKE_AP: U401.7 (BT_HOST_WAKE); also elsewhere on the board
/Application/HCI_CTS: R404.1, U401.44 (UART_CTS_N); also elsewhere on the board
/Application/HCI_RTS: R401.2, U401.41 (UART_RTS_N); also elsewhere on the board
/Application/HCI_RX: R403.2, U401.43 (UART_RXD); also elsewhere on the board
/Application/HCI_TX: R402.2, U401.42 (UART_TXD); also elsewhere on the board
/Application/SUS_CLK: R457.1; also elsewhere on the board
/Application/WIFI_CLK: U401.17 (SDIO_DATA_CLK); also elsewhere on the board
/Application/WIFI_CMD: R451.2, U401.16 (SDIO_DATA_CMD); also elsewhere on the board
/Application/WIFI_DAT0: R452.2, U401.18 (SDIO_DATA_0); also elsewhere on the board
/Application/WIFI_DAT1: R453.2, U401.19 (SDIO_DATA_1); also elsewhere on the board
/Application/WIFI_DAT2: R454.2, U401.14 (SDIO_DATA_2); also elsewhere on the board
/Application/WIFI_DAT3: R455.2, U401.15 (SDIO_DATA_3); also elsewhere on the board
/Application/WL_REG_ON: R450.2, U401.12 (WL_REG_ON); also elsewhere on the board
/Application/WL_WAKE_AP: U401.13 (WL_HOST_WAKE); also elsewhere on the board
/RL-SM02BD-8723BS/ANT: ANT401.1, C428.1, L405.1
/RL-SM02BD-8723BS/ANT_FILT: C427.1, L405.2, U401.2 (WL_BT_ANT)
/RL-SM02BD-8723BS/LPO: R457.2, R458.1, U401.24 (LPO)
/RL-SM02BD-8723BS/VDD_WIFI: C415.1, C416.1, R401.1, R402.1, R403.1, R404.2, R450.1, R451.1, R452.1, R453.1, R454.1, R455.1, R456.1, R458.2, R461.2, U401.9 (VBAT), U401.22 (VDDIO)
/RL-SM02BD-8723BS/VIN_LDO: C429.1, L403.1, U401.23 (VIN_LDO)
/RL-SM02BD-8723BS/XI: C402.1, U401.10 (XTAL_IN), Y401.1
/RL-SM02BD-8723BS/XO: C414.1, U401.11 (XTAL_OUT), Y401.3
GND: ANT401.2, ANT401.3, C402.2, C414.2, C415.2, C416.2, C427.2, C428.2, C429.2, R460.1, U401.1 (GND), U401.3 (GND), U401.20 (GND), U401.31 (GND), U401.33 (GND), U401.36 (GND), Y401.2, Y401.4; also elsewhere on the board
unnamed: L403.2, U401.21 (VIN_LDO_OUT)

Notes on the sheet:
CX1 = CX2 = 2(15pF - 2pF) = 26pF 22pF already in the bom

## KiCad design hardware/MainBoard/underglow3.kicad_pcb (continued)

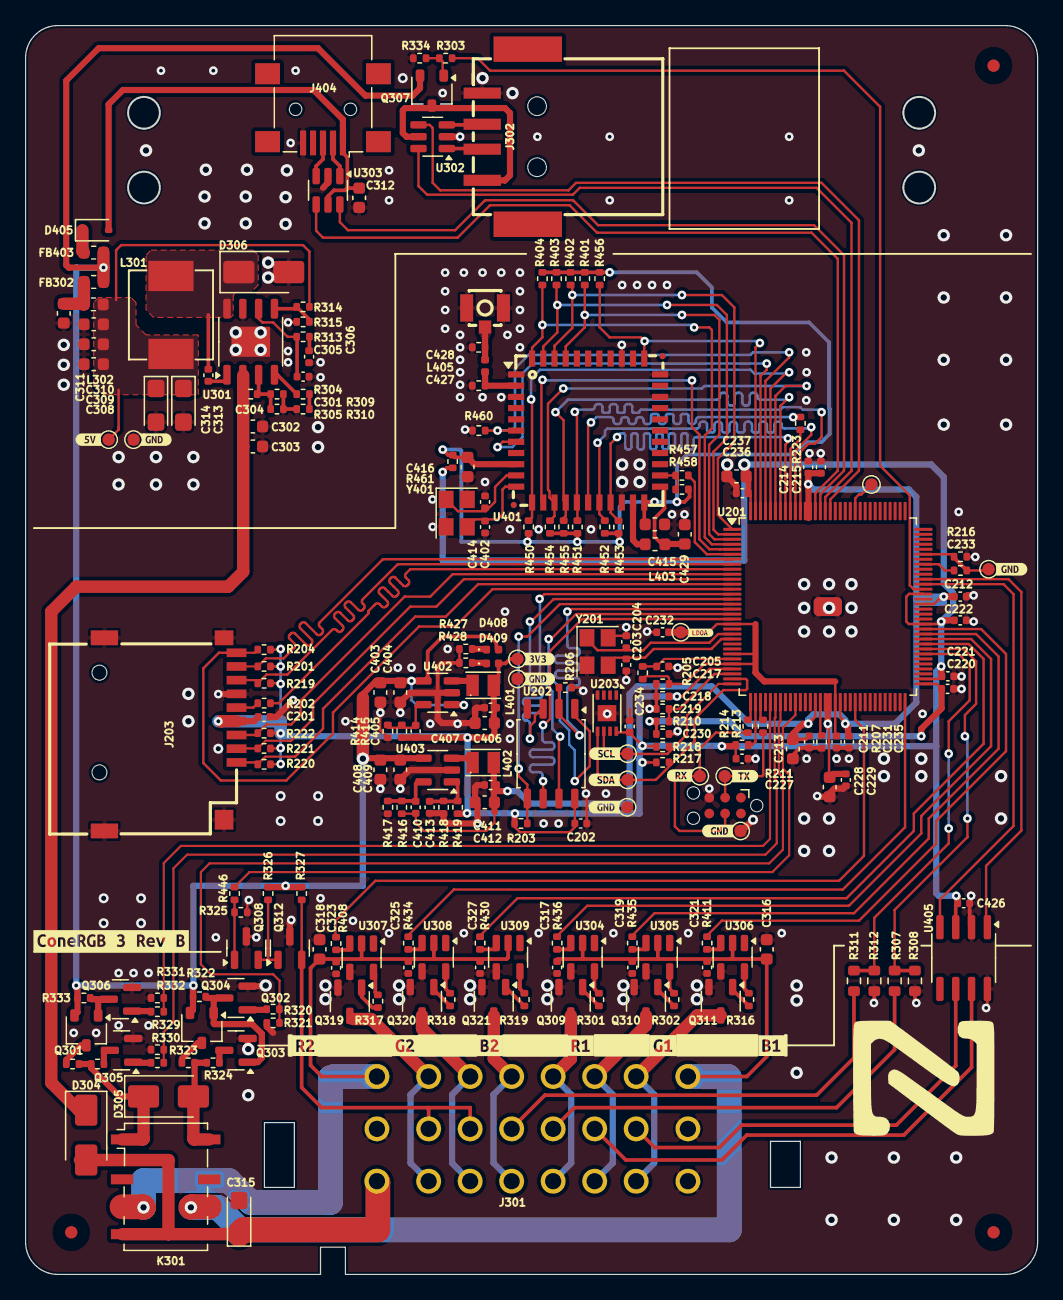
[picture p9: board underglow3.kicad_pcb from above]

Board: 4 copper layers, 81.2 x 100.2 mm, 238 parts (0 on the bottom side), 150 nets.

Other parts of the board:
Enclosure: TestPoint_Pad_D1.0mm
TP: GND; TestPoint_Pad_D1.0mm
TP#2: GND; TestPoint_Pad_D1.0mm
U201: T113-S3; LQFP-128_14x14mm_P0.4mm
kibuzzard-65F09AC9: G***; kibuzzard-65F09AC9
kibuzzard-65F09B04: G***; kibuzzard-65F09B04
kibuzzard-65F09B16: G***; kibuzzard-65F09B16
kibuzzard-65F09B27: G***; kibuzzard-65F09B27
kibuzzard-65F09B40: G***; kibuzzard-65F09B40
kibuzzard-65F09B51: G***; kibuzzard-65F09B51
kibuzzard-65F09C6B: G***; kibuzzard-65F09C6B
kibuzzard-65F09CD2: G***; kibuzzard-65F09CD2
kibuzzard-65F09CF9: G***; kibuzzard-65F09CF9
kibuzzard-65F09D0C: G***; kibuzzard-65F09D0C
kibuzzard-65F09D1C, kibuzzard-65F09D1C#2: G***; kibuzzard-65F09D1C
kibuzzard-65FE52BD: G***; kibuzzard-65FE52BD
kibuzzard-65FE521F: G***; kibuzzard-65FE521F
kibuzzard-65FE522B, kibuzzard-65FE522B#2: G***; kibuzzard-65FE522B
kibuzzard-65FEF020: G***; kibuzzard-65FEF020
kibuzzard-65FEF408: G***; kibuzzard-65FEF408
kibuzzard-65FEF568: G***; kibuzzard-65FEF568

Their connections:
+0v9: U201.46 (VDD-SYS0), U201.51 (VDD-SYS0), U201.81 (VDD-SYS2), U201.116 (VDD-CORE0), U201.117 (VDD-CORE1); also elsewhere on the board
+1V8A: U201.89 (AVCC); also elsewhere on the board
+3V3: U201.29 (LDO-IN), U201.66 (VCC-PD), U201.77 (VCC-TVOUT), U201.83 (VCC-IO), U201.128 (VCC-PG); also elsewhere on the board
/Application/AP_WAKE_BT: U201.125 (PG13); also elsewhere on the board
/Application/BT_EN: U201.127 (PG15); also elsewhere on the board
/Application/BT_WAKE_AP: U201.126 (PG14); also elsewhere on the board
/Application/CAN0_RX: U201.85 (PB3); also elsewhere on the board
/Application/CAN0_TX: U201.86 (PB2); also elsewhere on the board
/Application/DZQ: U201.47 (DZQ); also elsewhere on the board
/Application/HCI_CTS: U201.4 (PG9); also elsewhere on the board
/Application/HCI_RTS: U201.3 (PG8); also elsewhere on the board
/Application/HCI_RX: U201.2 (PG7); also elsewhere on the board
/Application/HCI_TX: U201.1 (PG6); also elsewhere on the board
/Application/I2C_SCL: U201.32 (PE12); also elsewhere on the board
/Application/I2C_SDA: U201.31 (PE13); also elsewhere on the board
/Application/LDOA_OUT: U201.20 (VCC-PLL), U201.26 (VCC-RTC), U201.28 (LDOA-OUT), U201.50 (VDD18-DRAM); also elsewhere on the board
/Application/LDOB_OUT: U201.30 (LDOB-OUT); also elsewhere on the board
/Application/LEDC: U201.42 (PE5); also elsewhere on the board
/Application/PWM0: U201.73 (PD16); also elsewhere on the board
/Application/PWM1: U201.74 (PD17); also elsewhere on the board
/Application/PWM2: U201.75 (PD18); also elsewhere on the board
/Application/PWM3: U201.76 (PD19); also elsewhere on the board
/Application/PWM4: U201.54 (PD20); also elsewhere on the board
/Application/PWM6: U201.64 (PD9); also elsewhere on the board
/Application/RELAY_COIL_GND: U201.38 (PE9); also elsewhere on the board
/Application/RELAY_COIL_VDC: U201.37 (PE10); also elsewhere on the board
/Application/RELAY_SW: U201.39 (PE8); also elsewhere on the board
/Application/RST: U201.27 (RST); also elsewhere on the board
/Application/SDCO0_CLK: U201.9 (PF2); also elsewhere on the board
/Application/SDCO0_CMD: U201.10 (PF3); also elsewhere on the board
/Application/SDCO0_D0: U201.8 (PF1); also elsewhere on the board
/Application/SDCO0_D1: U201.7 (PF0); also elsewhere on the board
/Application/SDCO0_D2: U201.12 (PF5); also elsewhere on the board
/Application/SDCO0_D3: U201.11 (PF4); also elsewhere on the board
/Application/SD_DET: U201.13 (PF6); also elsewhere on the board
/Application/SPI0_CLK: U201.19 (PC2); also elsewhere on the board
/Application/SPI0_CS0: U201.18 (PC3); also elsewhere on the board
/Application/SPI0_HLD: U201.14 (PC7); also elsewhere on the board
/Application/SPI0_MISO: U201.16 (PC5); also elsewhere on the board
/Application/SPI0_MOSI: U201.17 (PC4); also elsewhere on the board
/Application/SPI0_WP: U201.15 (PC6); also elsewhere on the board
/Application/SUS_CLK: U201.6 (PG11); also elsewhere on the board
/Application/UART0_RX: U201.33 (PE3); also elsewhere on the board
/Application/UART0_TX: U201.35 (PE2); also elsewhere on the board
/Application/USB0_DN: U201.114 (USB0-DM); also elsewhere on the board
/Application/USB0_DP: U201.115 (USB0-DP); also elsewhere on the board
/Application/USB1_DN: U201.113 (USB1-DM); also elsewhere on the board
/Application/USB1_DP: U201.112 (USB1-DP); also elsewhere on the board
/Application/USB_SW: U201.84 (PB4); also elsewhere on the board
/Application/VCC_DRAM: U201.48 (VCC-DRAM0), U201.49 (VCC-DRAM1), U201.65 (VCC-LVDS); also elsewhere on the board
/Application/VCC_PE: U201.34 (VCC-PE); also elsewhere on the board
/Application/WIFI_CMD: U201.118 (PG1); also elsewhere on the board
/Application/WIFI_DAT0: U201.119 (PG2); also elsewhere on the board
/Application/WIFI_DAT1: U201.121 (PG3); also elsewhere on the board
/Application/WIFI_DAT2: U201.123 (PG4); also elsewhere on the board
/Application/WIFI_DAT3: U201.122 (PG5); also elsewhere on the board
/Application/WL_REG_ON: U201.124 (PG12); also elsewhere on the board
/Application/WL_WAKE_AP: U201.5 (PG10); also elsewhere on the board
/Application/XI: U201.23 (DXIN); also elsewhere on the board
/Application/XO: U201.22 (DXOUT); also elsewhere on the board
/Power/PI1_DIV: U201.72 (PD15); also elsewhere on the board
/Power/PI2_DIV: U201.71 (PD14); also elsewhere on the board
GND: TP.1, TP#2.1, U201.129 (EP); also elsewhere on the board
GNDA: U201.91 (AGND); also elsewhere on the board
unnamed 127: U201.120 (PG0); also elsewhere on the board
unnamed 128: U201.107 (VCC-TVIN); also elsewhere on the board

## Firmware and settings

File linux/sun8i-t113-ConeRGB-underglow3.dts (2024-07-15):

// SPDX-License-Identifier: (GPL-2.0+ or MIT)
// Copyright (C) 2024 Connor Rigby <connorr@hey.com>

#include <dt-bindings/interrupt-controller/irq.h>

/dts-v1/;

#include <arm/allwinner/sun8i-t113s.dtsi>

#include <dt-bindings/gpio/gpio.h>
#include <dt-bindings/input/input.h>
#include <dt-bindings/leds/common.h>
#include <dt-bindings/pwm/pwm.h>

/ {
	model = "ConeRGB Underglow3";
	compatible = "allwinner,sun8i-t113s", "allwinner,sun8i";

	aliases {
		mmc0 = &mmc0;
		serial0 = &uart0;
		serial1 = &uart1;
		ethernet0 = &rtl8189ftv;
	};

	chosen {
		stdout-path = "serial0:115200n8";
	};

	/* board wide 5V supply directly from the USB-C socket */
	reg_vcc5v: regulator-5v {
		compatible = "regulator-fixed";
		regulator-name = "vcc-5v";
		regulator-min-microvolt = <5000000>;
		regulator-max-microvolt = <5000000>;
		regulator-always-on;
	};

	/* SY8008 DC/DC regulator on the board */
	reg_3v3: regulator-3v3 {
		compatible = "regulator-fixed";
		regulator-name = "vcc-3v3";
		regulator-min-microvolt = <3300000>;
		regulator-max-microvolt = <3300000>;
		vin-supply = <&reg_vcc5v>;
	};

	/* SY8008 DC/DC regulator on the board, also supplying VDD-SYS */
	reg_vcc_core: regulator-core {
		compatible = "regulator-fixed";
		regulator-name = "vcc-core";
		regulator-min-microvolt = <880000>;
		regulator-max-microvolt = <880000>;
		vin-supply = <&reg_vcc5v>;
	};

	reg_usb: regulator-usb {
		compatible = "regulator-fixed";
		regulator-name = "vbus-5v";
		regulator-min-microvolt = <5000000>;
		regulator-max-microvolt = <5000000>;
		gpio = <&pio 1 4 GPIO_ACTIVE_LOW>; /* PB4 */
		startup-delay-us = <1000000>; /* 1 second */
		off-on-delay-us = <1000000>; /* 1 second */
		enable-active-low;
	};

	leds {
		compatible = "gpio-leds";

		led-0 {
			color = <LED_COLOR_ID_BLUE>;
			function = LED_FUNCTION_STATUS;
			gpios = <&pio 3 22 GPIO_ACTIVE_LOW>; /* PD22 */
		};
	};

    led-controller@0 {
        compatible = "pwm-leds-multicolor";
		pinctrl-0 = <&pwm1_pd17_pins>, <&pwm2_pd18_pins>, <&pwm3_pd19_pins>;
		pinctrl-names = "default";
		multi-led {
			color = <LED_COLOR_ID_RGB>;
            function = LED_FUNCTION_INDICATOR;
            max-brightness = <100000>;
			label = "underglow:0";
			led-red {
				color = <LED_COLOR_ID_RED>;
				pwms = <&pwm 1 100000 0>;
				max-brightness = <100000>;
			};
			led-green {
				color = <LED_COLOR_ID_GREEN>;
				pwms = <&pwm 2 100000 0>;
				max-brightness = <100000>;
			};
			led-glue {
				color = <LED_COLOR_ID_BLUE>;
				pwms = <&pwm 3 100000 0>;
				max-brightness = <100000>;
			};
		};
    };

    led-controller@1 {
        compatible = "pwm-leds-multicolor";
		pinctrl-0 = <&pwm4_pd20_pins>, <&pwm6_pd9_pins>, <&pwm0_pd16_pins>;
		pinctrl-names = "default";
		multi-led {
			color = <LED_COLOR_ID_RGB>;
            function = LED_FUNCTION_INDICATOR;
            max-brightness = <100000>;
			label = "underglow:1";
			led-red {
				color = <LED_COLOR_ID_RED>;
				pwms = <&pwm 4 100000 0>;
				max-brightness = <100000>;
			};
			led-green {
				color = <LED_COLOR_ID_GREEN>;
				pwms = <&pwm 6 100000 0>;
				max-brightness = <100000>;
			};
			led-glue {
				color = <LED_COLOR_ID_BLUE>;
				pwms = <&pwm 0 100000 0>;
				max-brightness = <100000>;
			};
		};
    };

	buttons {
		compatible = "gpio-keys";
		autorepeat;

		button@1 {
			label = "User Input 1";
			linux,code = <KEY_A>;
			gpios = <&pio 3 15 0>; /* PD15 */
		};

		button@2 {
			label = "User Input 2";
			linux,code = <KEY_B>;
			gpios = <&pio 3 14 0>; /* PD14 */
		};
	};

	wifi_pwrseq: wifi-pwrseq {
		compatible = "mmc-pwrseq-simple";
		reset-gpios = <&pio 6 12 GPIO_ACTIVE_LOW>; /* PG12 */
		post-power-on-delay-ms = <200>;
	};
};

&dcxo {
	clock-frequency = <24000000>;
};

&cpu0 {
	cpu-supply = <&reg_vcc_core>;
	clock-frequency = <1200000000>;
};

&cpu1 {
	cpu-supply = <&reg_vcc_core>;
	clock-frequency = <1200000000>;
};

&wdt {
	status = "okay";
};

&pio {
	vcc-pb-supply = <&reg_3v3>;
	vcc-pc-supply = <&reg_3v3>;
	vcc-pd-supply = <&reg_3v3>;
	vcc-pe-supply = <&reg_3v3>;
	vcc-pf-supply = <&reg_3v3>;
	vcc-pg-supply = <&reg_3v3>;

	uart0_pe2_pins: uart0-pe2-pins {
		pins = "PE2", "PE3";
		function = "uart0";
	};

	i2c2_pe12_pins: i2c2-pe12-pins {
		pins = "PE12", "PE13";
		function = "i2c2";
	};

	pwm0_pd16_pins: pwm0-pd16-pins {
		pins = "PD16";
		function = "pwm0";
	};

	pwm1_pd17_pins: pwm1-pd16-pins {
		pins = "PD17";
		function = "pwm1";
	};

	pwm2_pd18_pins: pwm2-pd18-pins {
		pins = "PD18";
		function = "pwm2";
	};

	pwm3_pd19_pins: pwm2-pd19-pins {
		pins = "PD19";
		function = "pwm3";
	};

	pwm4_pd20_pins: pwm4-pd20-pins {
		pins = "PD20";
		function = "pwm4";
	};

	/omit-if-no-ref/
	pwm5_pd21_pins: pwm5-pd21-pins {
		pins = "PD21";
		function = "pwm5";
	};

	pwm6_pd9_pins: pwm6-pd9-pins {
		pins = "PD9";
		function = "pwm6";
	};

	/omit-if-no-ref/
	pwm7_pd22_pins: pwm7-pd22-pins {
		pins = "PD22";
		function = "pwm7";
	};

	ledc_pe5_pin: ledc-pe5-pin {
		pins = "PE5";
		function = "ledc";
	};

	spi0_cs0_pc_pin: spi0-cs0-pc-pin {
		pins = "PC3";
		function = "spi0";
	};
};

&pwm {
	status = "okay";
};

&ledc {
	pinctrl-0 = <&ledc_pe5_pin>;
	pinctrl-names = "default";
	status = "okay";
	allwinner,pixel-format = "grb";
	allwinner,t0h-ns = "320";
	allwinner,t0l-ns = "800";
	allwinner,t1h-ns = "840";
	allwinner,t1l-ns = "400";
	allwinner,treset-ns = "300000";
	label = "underglow:ledc";
};

&uart0 {
	pinctrl-0 = <&uart0_pe2_pins>;
	pinctrl-names = "default";
	status = "okay";
};

&uart1 {
	uart-has-rtscts;
	pinctrl-0 = <&uart1_pg6_pins>, <&uart1_pg8_rts_cts_pins>;
	pinctrl-names = "default";
	status = "okay";

	bluetooth {
		compatible = "realtek,rtl8723bs-bt";
		device-wake-gpios = <&pio 6 13 GPIO_ACTIVE_HIGH>; /* PG13 */
		host-wake-gpios =  <&pio 6 14 GPIO_ACTIVE_HIGH>; /* PG14 */
		enable-gpios = <&pio 6 15 GPIO_ACTIVE_HIGH>; /* PG15 */
		max-speed = <115200>;
		// max-speed = <1500000>;
		status = "okay";
	};
};

&i2c2 {
	pinctrl-0 = <&i2c2_pe12_pins>;
	pinctrl-names = "default";
	status = "okay";
	clock-frequency = <62000>;
};

&mmc0 {
	pinctrl-0 = <&mmc0_pins>;
	pinctrl-names = "default";
	vmmc-supply = <&reg_3v3>;
	cd-gpios = <&pio 5 6 GPIO_ACTIVE_LOW>;
	disable-wp;
	bus-width = <4>;
	status = "okay";
};

&mmc1 {
	pinctrl-0 = <&mmc1_pins>;
	pinctrl-names = "default";

	/* SDIO to WiFi module */
	vmmc-supply = <&reg_3v3>;
	mmc-pwrseq = <&wifi_pwrseq>;
	bus-width = <4>;
	non-removable;
	status = "okay";

	rtl8189ftv: wifi@1 {
		reg = <1>;
		interrupt-parent = <&pio>;
		interrupts = <6 10 IRQ_TYPE_LEVEL_LOW>; /* PG10 = WL_WAKE_AP */
		interrupt-names = "host-wake";
	};
};

&usb_otg {
	dr_mode = "peripheral";
	status = "okay";
};

&usbphy {
	usb1_vbus-supply = <&reg_usb>;
	status = "okay";
};

&ehci1 {
	status = "okay";
};

&ohci1 {
	status = "okay";
};

&can0 {
	pinctrl-names = "default";
	pinctrl-0 = <&can0_pins>;
	status = "okay";
};

&spi0 {
	status = "disabled";
};

&mixer0 {
	status = "disabled";
};

&tcon_top {
	status = "disabled";
};

&tcon_lcd0 {
	status = "disabled";
};
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

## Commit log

2024-02-29 enable CAN and LEDC
2024-03-20 enable PWM
2024-03-21 enable pwm7
2024-03-23 Initial hardware release
    [Power.kicad_sch, RL-SM02BD-8723BS.kicad_sch, Simulation.kicad_pcb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]
2024-03-30 Bringup updates
    * Enable ledc
    * Enable temporary rtl wifi driver
    * Enable kernel bluetooth
    * Enable ipv6
2024-07-21 Remove unused sun6i rtc driver
